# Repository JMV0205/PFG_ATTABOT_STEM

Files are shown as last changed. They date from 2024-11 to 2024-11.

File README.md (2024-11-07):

# PROYECTO FINAL DE GRADUACION ATTABOT STEM: Jimena Murillo Vargas
# Resumen
El rediseño del Atta-Bot STEM se centró en transformar el robot educativo en una herramienta más precisa, segura y funcional para entornos de aprendizaje. A través de un análisis técnico, se identificaron áreas de mejora que llevaron al desarrollo de un chasis robusto, diseñado para soportar el uso constante y facilitar la integración de herramientas educativas, incluso en condiciones de alta manipulación.
Una de las principales mejoras es la incorporación de un marcador, que permite al robot realizar actividades de trazado y dibujo, enriqueciendo su funcionalidad en la enseñanza. Además, se implementó un algoritmo de control proporcional-integral (PI), sustentado matemáticamente, que optimiza la precisión en los movimientos del robot, contribuyendo a un funcionamiento eficiente en diversas aplicaciones. La validación del prototipo demostró que cumple con los estándares técnicos establecidos, confirmando su aptitud como recurso didáctico en la enseñanza de conceptos STEM.

**Palabras Clave:** Robótica Educativa, Atta-Bot STEM, Controlador PI, Chasis, Dibujo interactivo. 

# Objetivos
**General**
1.	Adaptar el robot educativo del proyecto Atta-Bot STEM para que sea preciso, protegido y con mayor funcionalidad, para un entorno educativo de manipulación constante, que el prototipo actual.

**Específicos**

1.1	 Evaluar el robot Atta-Bot STEM en función de los criterios clave para un robot educativo efectivo para el diagnóstico de falencias.

1.2	 Diseñar un chasis protector para que sea adecuado en un entorno de enseñanza.

1.3	 Diseñar un algoritmo de control que mejore la precisión de los movimientos del robot ante condiciones de uso delimitadas.

1.4	 Validar el rediseño del robot Atta-Bot STEM para la comprobación del cumplimiento de los estándares educativos y técnicos establecidos en el proyecto Atta-Bot STEM.

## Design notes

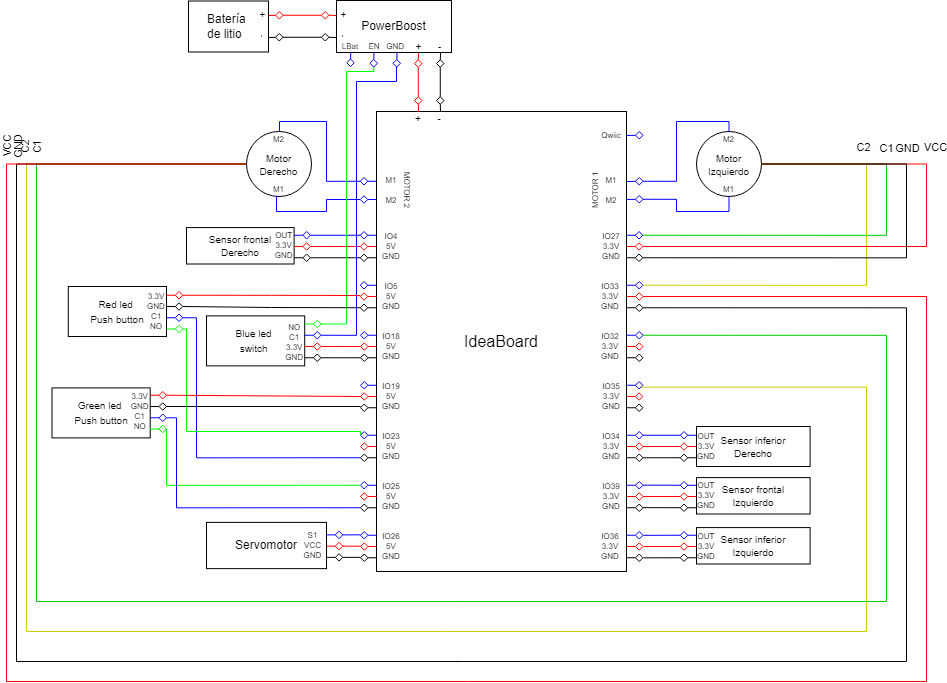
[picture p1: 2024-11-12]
Entregables/Diagrama electrico/Diagrama_electrico_PFG.png

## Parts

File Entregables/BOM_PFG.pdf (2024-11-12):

Cantidad | Nombre | # de Parte | Link | Costo
2 | Motor DC con
encoder | ROB-CB0N20 | https://www.crcibernetica.com/n20-gearmotor-with-encoder-and-wheel/ $14.95
1 | Batería Lipo | ADA-328 | https://www.crcibernetica.com/lithium-ion-polymer-battery-3-7v-
| | | 2500mah/ | $17.95
1 | Boost Battery
| Manager | ADA-2465 | https://www.crcibernetica.com/powerboost-1000-charger-rechargeable-5v-
| | | lipo-usb-boost-1a-1000c/ | $32.95
2 | Soporte Motor | ROB-CB02443 | https://www.crcibernetica.com/micro-gearmotor-support-bracket/ | $0.75
1 | Ball Caster | ROB-CB1818 | https://www.crcibernetica.com/3pi-n20-ball-caster/ | $2.75
1 | IdeaBoard | ROB-CBIB01 | https://www.crcibernetica.com/crcibernetica-ideaboard/ | $39.95
1 | Servomotor MG90S | MG90S | https://www.crcibernetica.com/mg90s-micro-servo-with-metal-gears/ | $6.95
2 | Infrarrojo delantero | SEN-CB0006 | https://www.crcibernetica.com/infrared-obstacle-avoidance-module/ | $2.95
2 | Infrarrojo abajo | SEN-CB0005 | https://www.crcibernetica.com/track-sensor-module/ | $1.95
1 | Kit conectores | KIT-CB0012 | https://www.crcibernetica.com/dupont-connector-assorted-kit/ | $8.95
1 | Kit espaciadores | TOL-CB0513 | https://www.crcibernetica.com/m3-nylon-screw-black-hex-screw-nut-nylon-pcb-
| | | standoff-assortment-kit-250pcs/ | $15.95
1 | Ribon Cable | CAB-10646 | https://www.crcibernetica.com/ribbon-cable-6-wire-15ft/ | $4.50
1 | Red Led push button | - | https://www.amazon.com/dp/B0C1GM39C2?ref=ppx_yo2ov_dt_b_fed_asin_title&t
| | | h=1 | $8.99
1 | Green Led push
| button | - | https://www.amazon.com/dp/B0C1GQ4JLB?ref=ppx_yo2ov_dt_b_fed_asi
| | | n_title&th=1 | $9.99
1 | Blue Led Switch | - | https://www.amazon.com/dp/B0CQ421KVZ?ref=ppx_yo2ov_dt_b_fed_asi
| | | n_title | $9.90

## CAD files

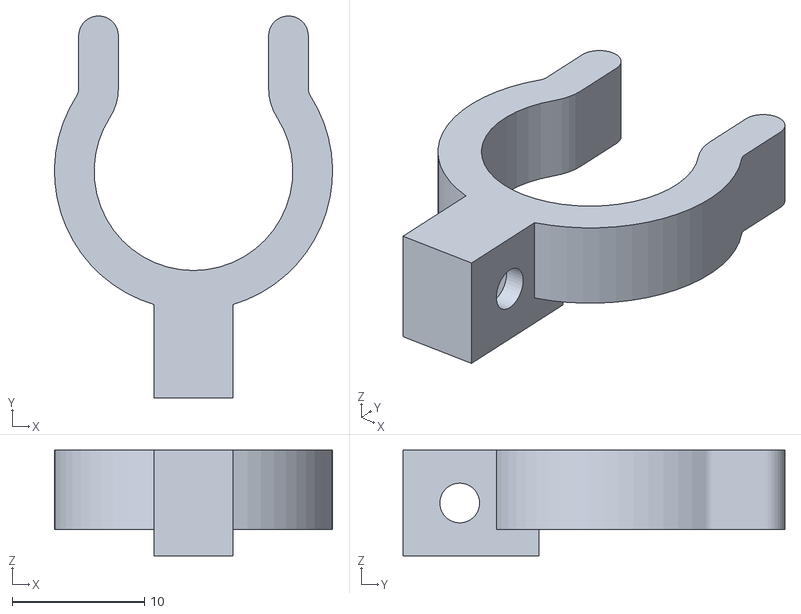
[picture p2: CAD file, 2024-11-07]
Entregables/Chasis/STL_DSK_PLANOS_CORTE/Sujetador_De_Marcador_2Largo_FULL.STL
21.0 x 28.8 x 8.00

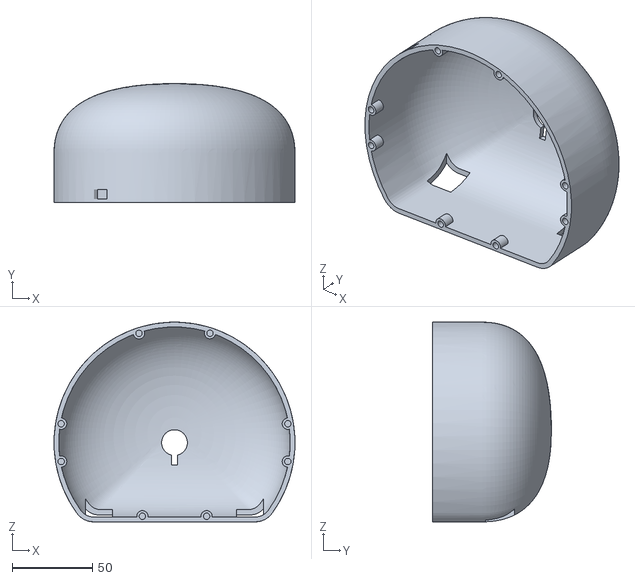
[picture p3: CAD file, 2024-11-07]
Entregables/Chasis/STL_DSK_PLANOS_CORTE/Prueba_chasis_Full.STL
150.0 x 74.0 x 124.3

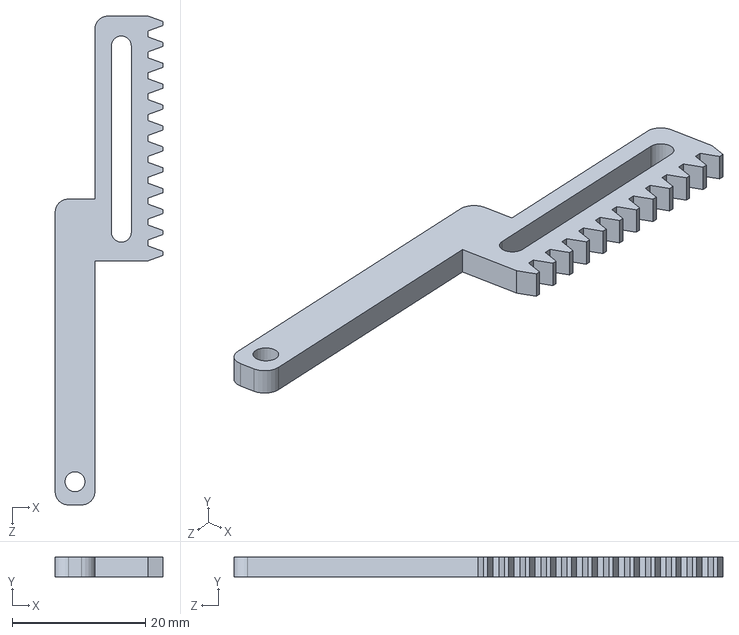
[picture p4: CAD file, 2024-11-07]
Entregables/Chasis/Pieza_de_cremallera_Lapicero_FULL.SLDPRT
16.2 x 3.00 x 73.5 mm

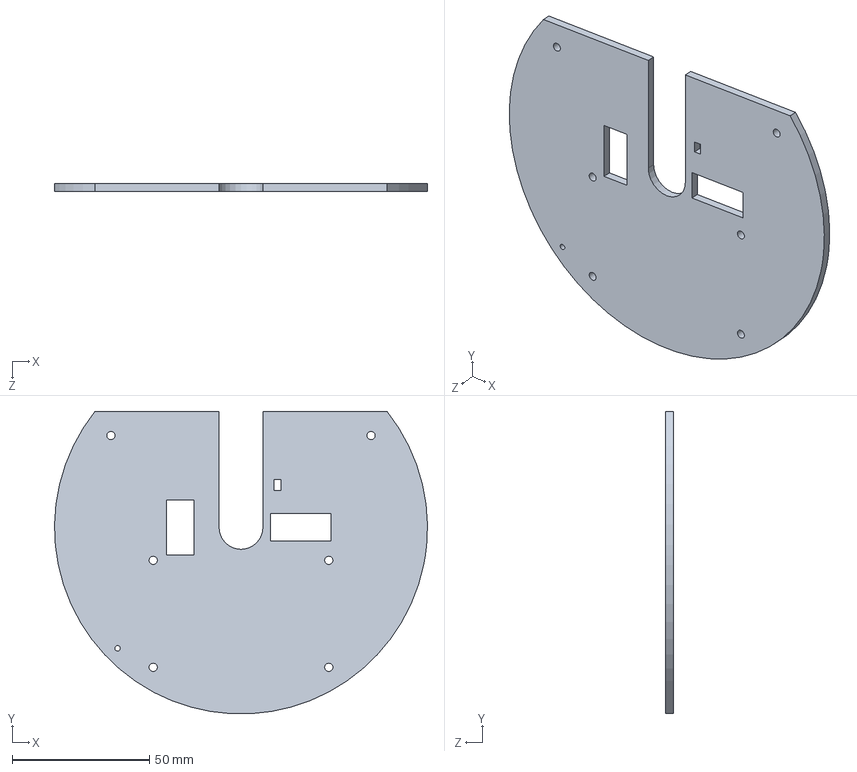
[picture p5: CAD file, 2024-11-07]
Entregables/Chasis/Nivel_interno_V2.SLDPRT
136.0 x 110.2 x 3.00 mm

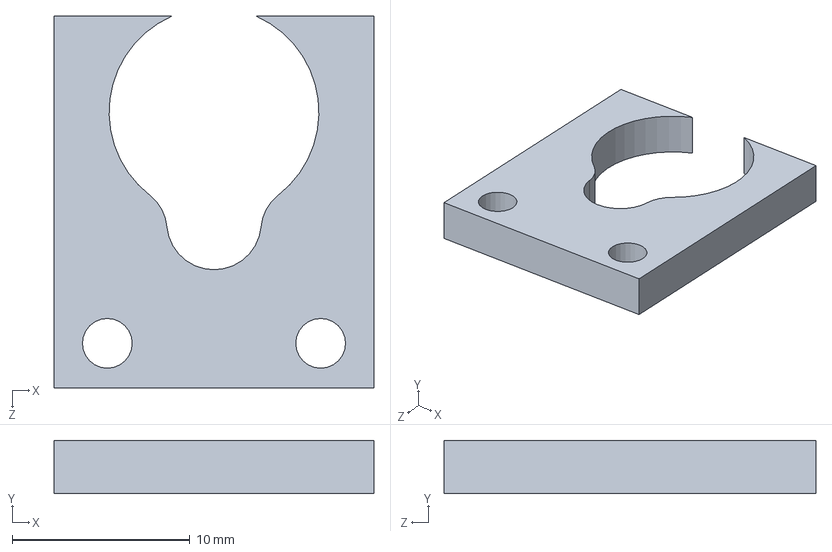
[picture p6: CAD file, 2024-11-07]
Entregables/Chasis/Pieza_SujecionMotorLift_5_final_si.SLDPRT
18.0 x 3.00 x 20.9 mm

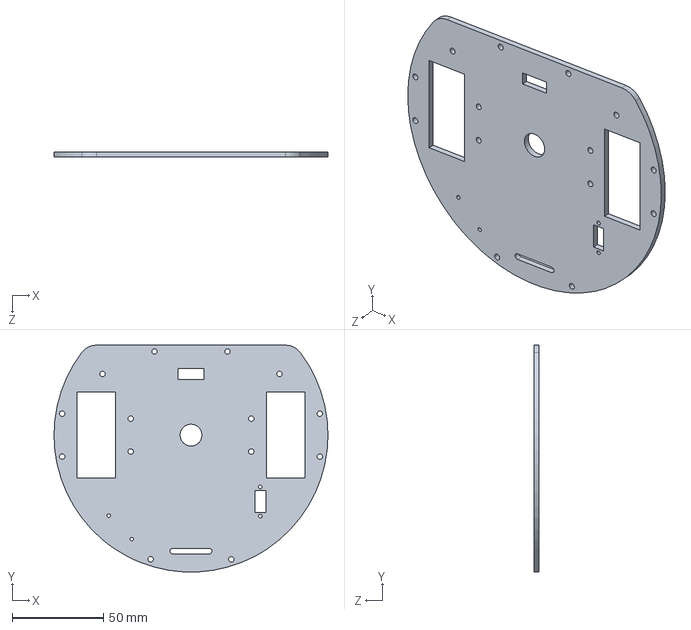
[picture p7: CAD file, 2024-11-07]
Entregables/Chasis/Base_Chasis_V3.SLDPRT
150.0 x 124.2 x 3.00 mm

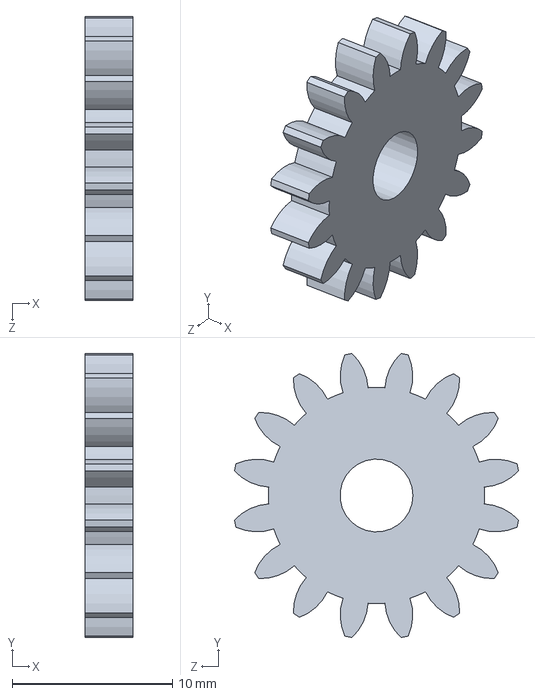
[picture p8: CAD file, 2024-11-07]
Entregables/Chasis/Pieza_EngraneLift_2.SLDPRT
3.00 x 17.7 x 17.7 mm

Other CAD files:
Entregables/Chasis/Sujetador_De_Marcador_2Largo_FULL.SLDPRT
Entregables/Chasis/Prueba_chasis_FULL.SLDPRT

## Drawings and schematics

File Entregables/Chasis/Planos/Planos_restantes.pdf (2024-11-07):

4 | 1 3 | 2

E

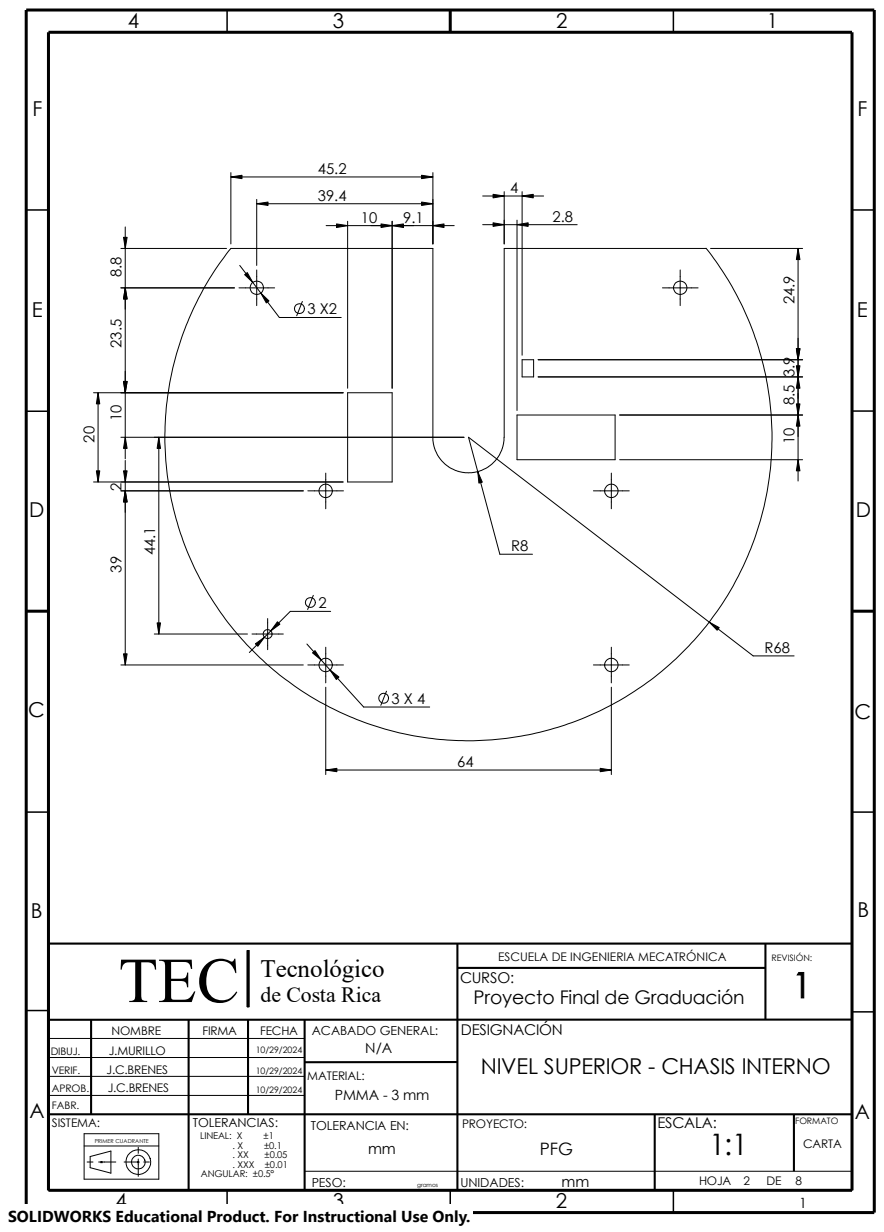
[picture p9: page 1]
Tecnológico TEC; PRIMER CUADRANTE; PMMA - 3 mm; REVISIÓN:; MATERIAL:

ESCUELA DE INGENIERIA MECATRÓNICA
CURSO:
Proyecto Final de Graduación

de Costa Rica

NOMBRE | FIRMA | FECHA | ACABADO GENERAL: N/A | DESIGNACIÓN NIVEL SUPERIOR - CHASIS INTERNO

DIBUJ. | J.MURILLO | | 10/29/2024
VERIF. | J.C.BRENES | | 10/29/2024
APROB. | J.C.BRENES | | 10/29/2024
FABR.
SISTEMA: | | | TOLERANCIAS: LINEAL: X ±1 . X ±0.1 . XX ±0.05 . XXX ±0.01 ANGULAR: ±0.5° | TOLERANCIA EN: mm | PFG | ESCALA: 1:1 | FORMATO PROYECTO: CARTA

PESO: gramos | mm UNIDADES: | HOJA 2 DE 8

SOLIDWORKS Educational Product. For Instructional Use Only.

E

F

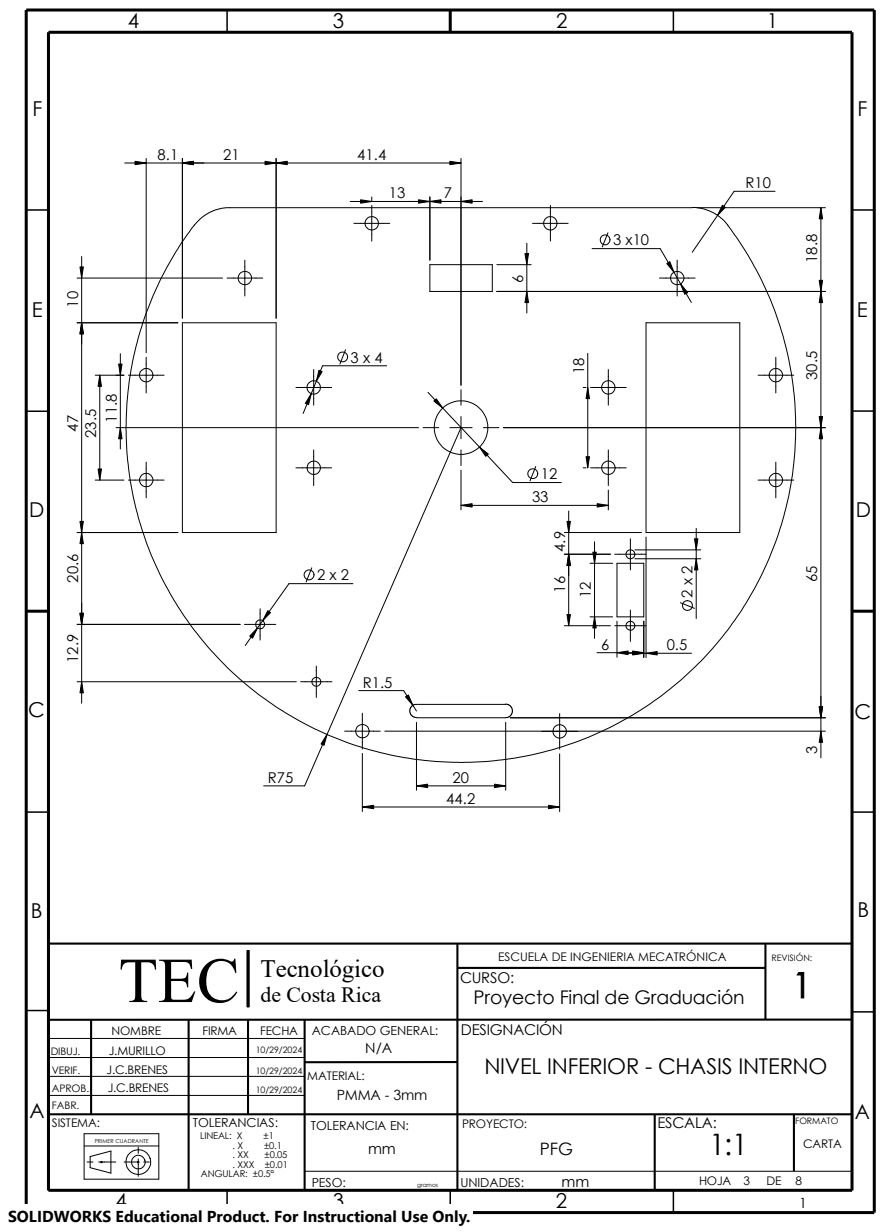
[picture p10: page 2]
Tecnológico TEC; PMMA - 3mm; REVISIÓN:; MATERIAL:

ESCUELA DE INGENIERIA MECATRÓNICA
CURSO:
Proyecto Final de Graduación

de Costa Rica

NOMBRE | FIRMA | FECHA | ACABADO GENERAL: N/A | DESIGNACIÓN NIVEL INFERIOR - CHASIS INTERNO

DIBUJ. | J.MURILLO | | 10/29/2024
VERIF. | J.C.BRENES | | 10/29/2024
APROB. | J.C.BRENES | | 10/29/2024
FABR.
SISTEMA: | | | TOLERANCIAS: | TOLERANCIA EN: | | ESCALA: 1:1 | FORMATO PROYECTO:

E

F

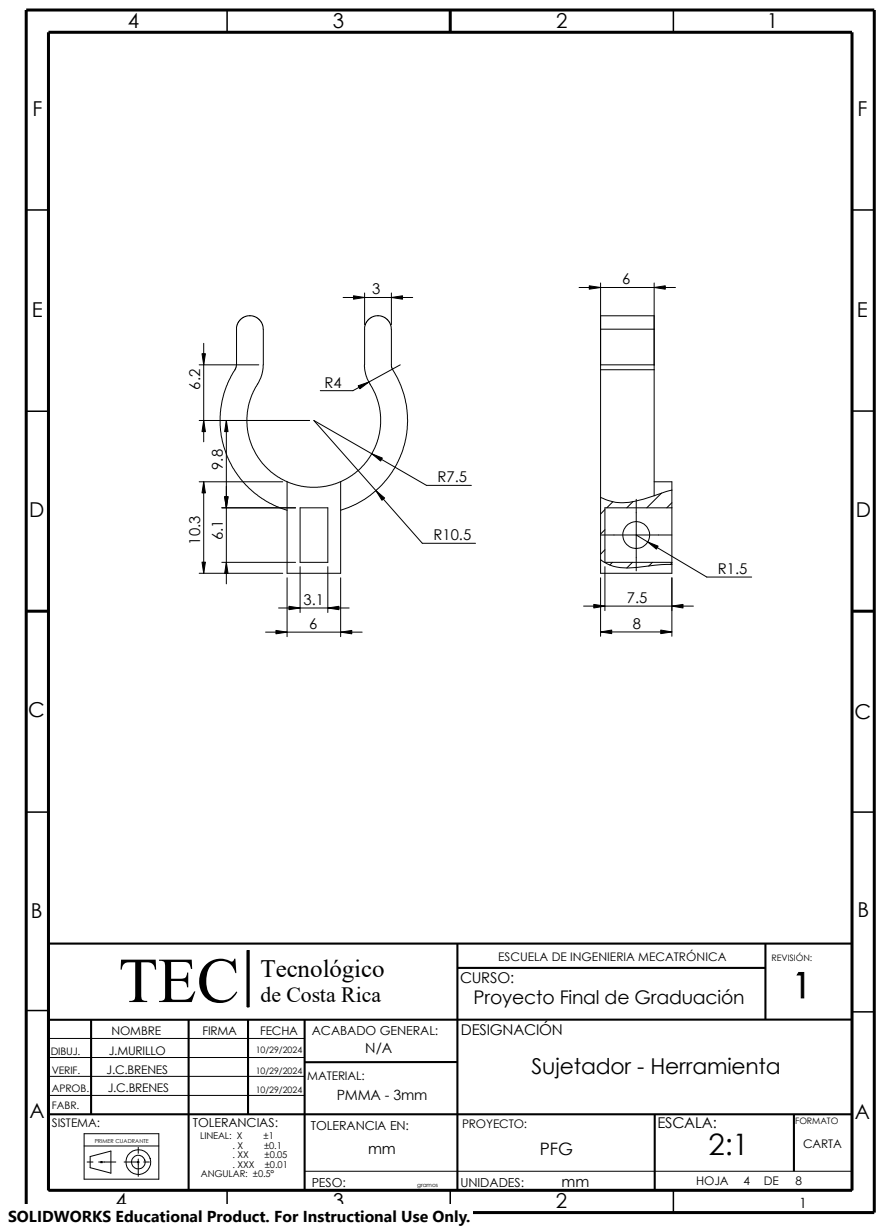
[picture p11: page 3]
Tecnológico TEC; PMMA - 3mm; REVISIÓN:; MATERIAL:

ESCUELA DE INGENIERIA MECATRÓNICA
CURSO:
Proyecto Final de Graduación

de Costa Rica

NOMBRE | FIRMA | FECHA | ACABADO GENERAL: N/A | DESIGNACIÓN Sujetador - Herramienta

DIBUJ. | J.MURILLO | | 10/29/2024
VERIF. | J.C.BRENES | | 10/29/2024
APROB. | J.C.BRENES | | 10/29/2024
FABR.
SISTEMA: | | | TOLERANCIAS: | TOLERANCIA EN: | | ESCALA: 2:1 | FORMATO PROYECTO:

18

E

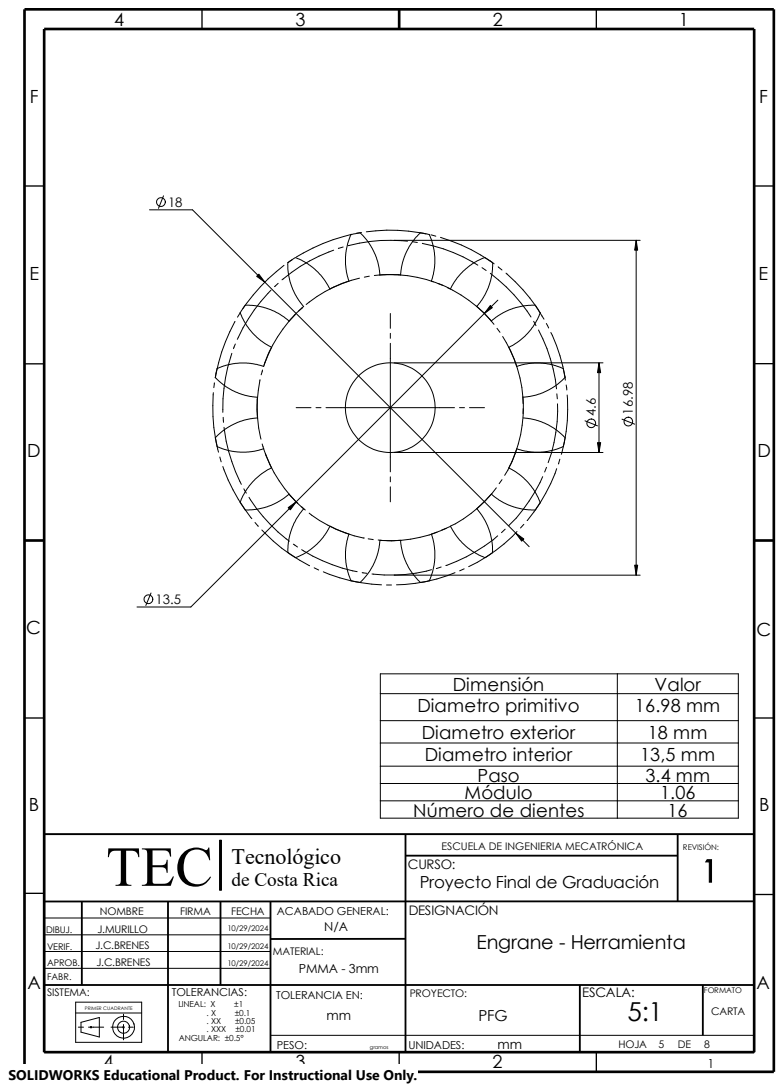
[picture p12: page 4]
Tecnológico TEC; PMMA - 3mm; REVISIÓN:; MATERIAL:; Diametro exterior; Número de dientes

Dimensión | Valor
Diametro primitivo | 16.98 mm

Diametro interior | 13,5 mm
Paso | 3.4 mm
Módulo | 1.06

ESCUELA DE INGENIERIA MECATRÓNICA
CURSO:
Proyecto Final de Graduación

de Costa Rica

NOMBRE | FIRMA | FECHA | ACABADO GENERAL: N/A | DESIGNACIÓN Engrane - Herramienta

DIBUJ. | J.MURILLO | | 10/29/2024
VERIF. | J.C.BRENES | | 10/29/2024
APROB. | J.C.BRENES | | 10/29/2024
FABR.
SISTEMA: | | | TOLERANCIAS: | TOLERANCIA EN: | | ESCALA: 5:1 | FORMATO PROYECTO:

E

F

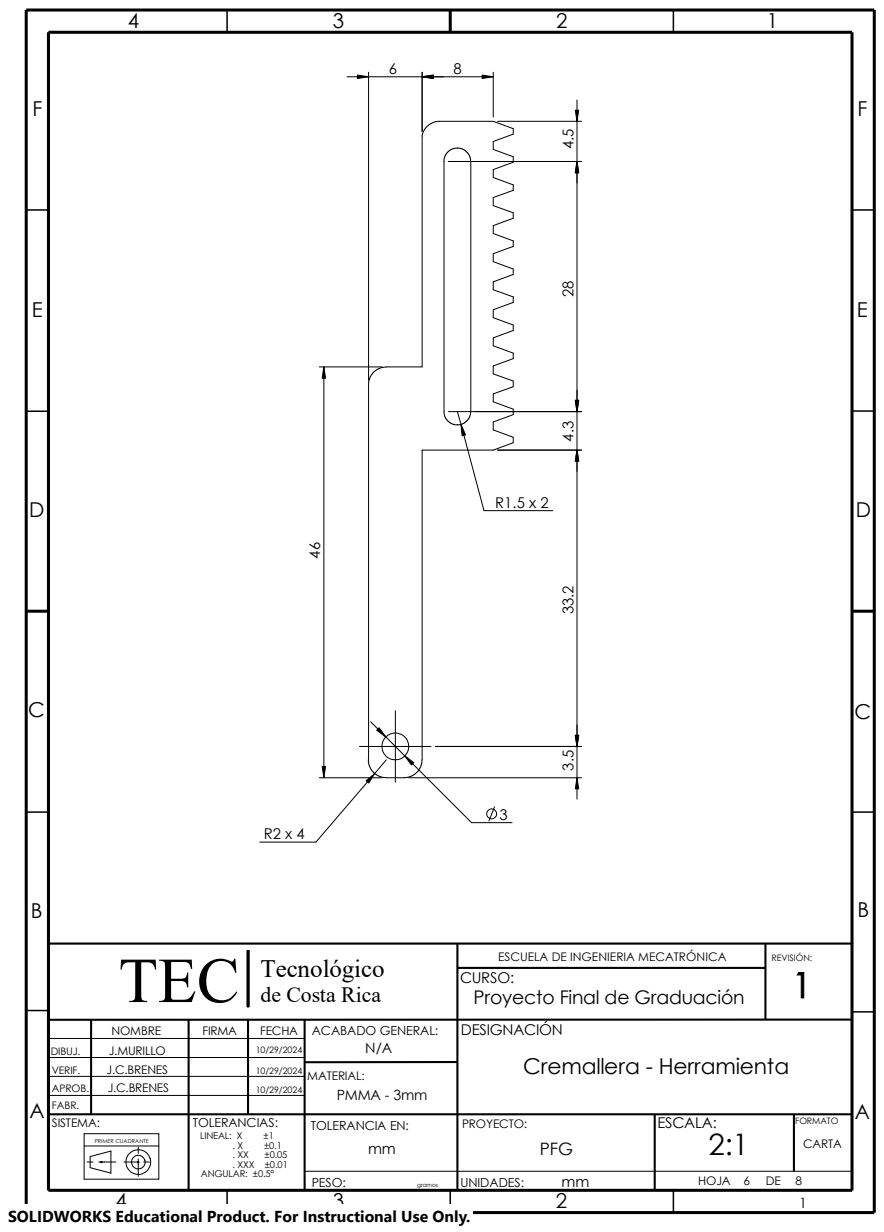
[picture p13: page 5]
Tecnológico TEC; PMMA - 3mm; REVISIÓN:; MATERIAL:

ESCUELA DE INGENIERIA MECATRÓNICA
CURSO:
Proyecto Final de Graduación

de Costa Rica

NOMBRE | FIRMA | FECHA | ACABADO GENERAL: N/A | DESIGNACIÓN Cremallera - Herramienta

DIBUJ. | J.MURILLO | | 10/29/2024
VERIF. | J.C.BRENES | | 10/29/2024
APROB. | J.C.BRENES | | 10/29/2024
FABR.
SISTEMA: | | | TOLERANCIAS: | TOLERANCIA EN: | | ESCALA: | FORMATO PROYECTO:

E

F

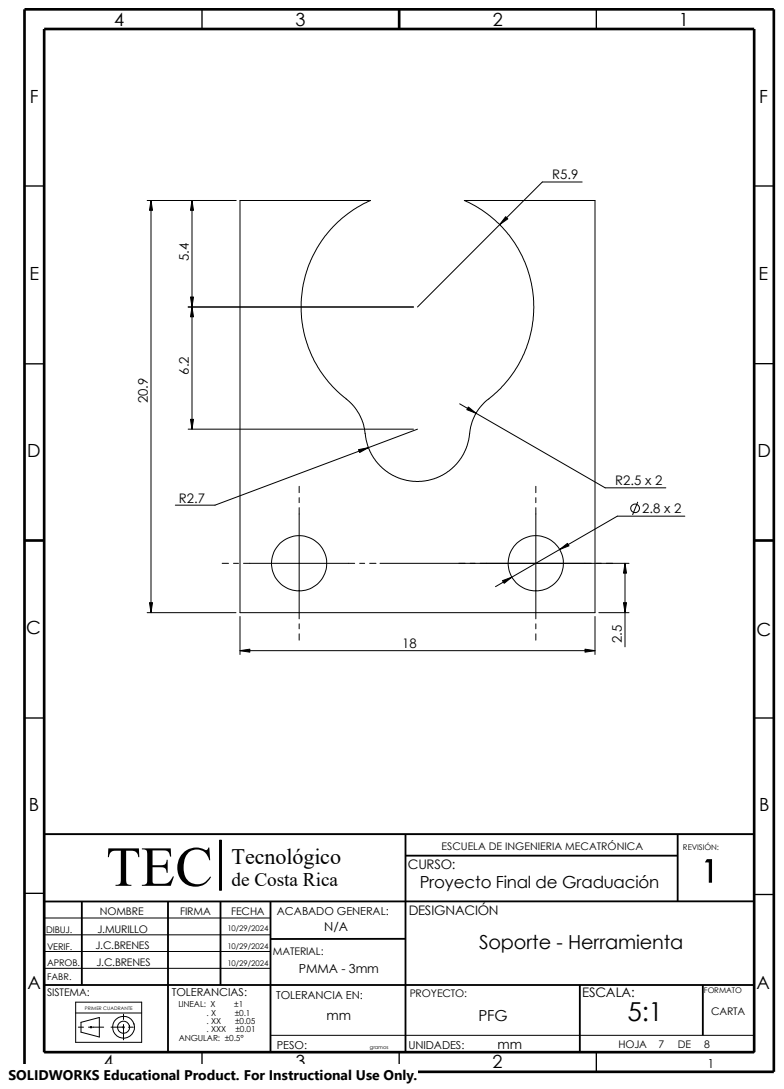
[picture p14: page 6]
Tecnológico TEC; PMMA - 3mm; REVISIÓN:; MATERIAL:

ESCUELA DE INGENIERIA MECATRÓNICA
CURSO:
Proyecto Final de Graduación

de Costa Rica

NOMBRE | FIRMA | FECHA | ACABADO GENERAL: N/A | DESIGNACIÓN Soporte - Herramienta

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

E

F

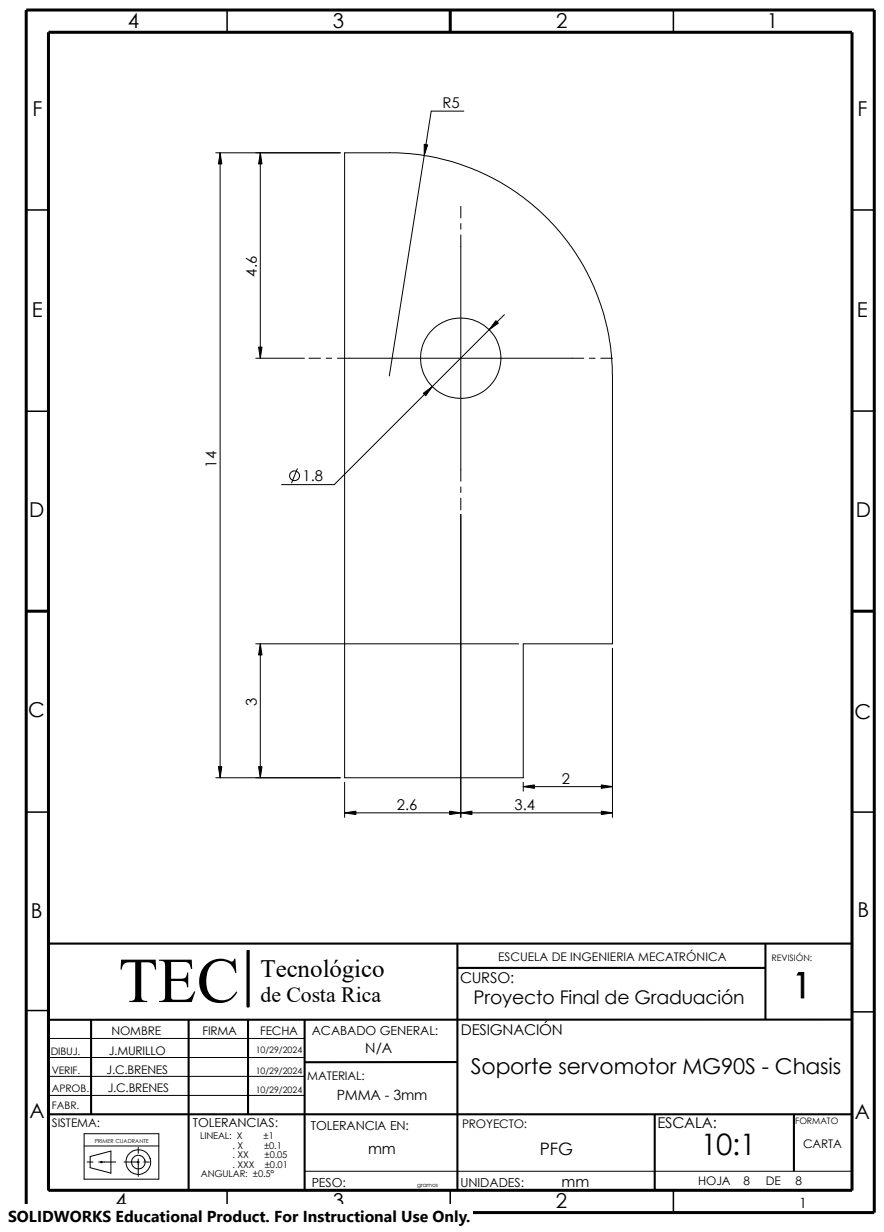
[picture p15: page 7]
Tecnológico TEC; PMMA - 3mm; REVISIÓN:; MATERIAL:

ESCUELA DE INGENIERIA MECATRÓNICA
CURSO:
Proyecto Final de Graduación

de Costa Rica

NOMBRE | FIRMA | FECHA | ACABADO GENERAL: N/A | DESIGNACIÓN Soporte servomotor MG90S - Chasis

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

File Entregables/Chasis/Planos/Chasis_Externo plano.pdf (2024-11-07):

B

A

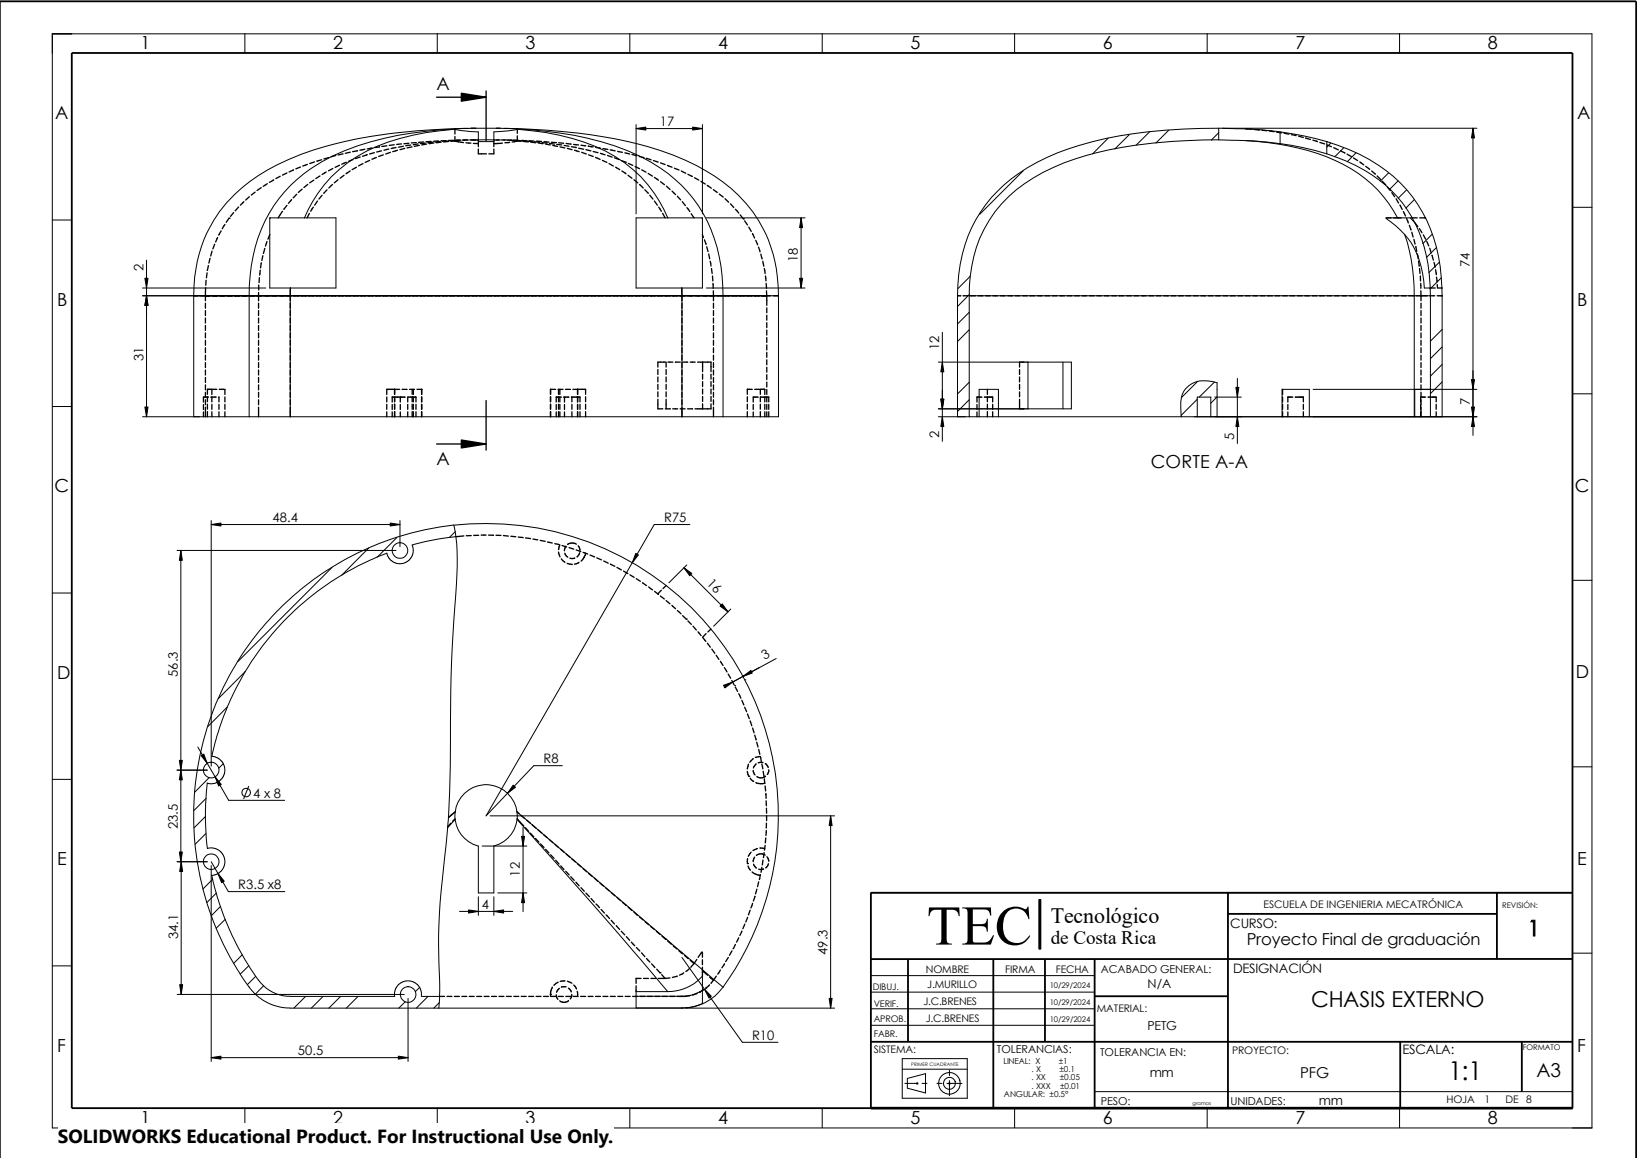
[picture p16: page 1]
Tecnológico TEC; PRIMER CUADRANTE; CURSO:; MATERIAL:; REVISIÓN:; PETG; HOJA; CORTE A-A

ESCUELA DE INGENIERIA MECATRÓNICA
Proyecto Final de graduación

de Costa Rica

NOMBRE | FIRMA | FECHA | ACABADO GENERAL: N/A | DESIGNACIÓN CHASIS EXTERNO

DIBUJ. | J.MURILLO | | 10/29/2024
VERIF. | J.C.BRENES | | 10/29/2024
APROB. | J.C.BRENES | | 10/29/2024
FABR.
SISTEMA: | | | LINEAL: X ±1 . X ±0.1 . XX ±0.05 . XXX ±0.01 ANGULAR: ±0.5° | TOLERANCIA EN: TOLERANCIAS: mm | PROYECTO: PFG | ESCALA: 1:1 | FORMATO A3

PESO: gramos | UNIDADES: mm

SOLIDWORKS Educational Product. For Instructional Use Only.

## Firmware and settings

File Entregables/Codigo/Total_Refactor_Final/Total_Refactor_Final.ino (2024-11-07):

#include <ESP32Servo.h>

// Robot constants
const int samplingTime = 25; // units: miliseconds
const float pulsesPerRev = 574; // number of pulses from a single encoder output
const float wheelRadius = 22.5; // Wheel circumference = 139.5mm
const float distanceWheelToWheel = 104;
const float distanceCenterToWheel = distanceWheelToWheel / 2 ; // Turning radius of the robot, distance in mm between the center and one wheel

// Constants for PID control with samplingTime = 25ms
const float targetSpeed = 120.0; // Target speed for the robot in mm/s
const float kpSpeed = 0.75; // Proportional constant for speed control
const float kiSpeed = 2; // Integral constant for speed control
const float kdSpeed = 0.0; // Derivative constant for speed control (set to zero for no derivative action)

// Constants for PID control implementation
const int minIntegralErrorSpeed = -255; // Minimum value for integral error to avoid windup
const int maxIntegralErrorSpeed = 255; // Maximum value for integral error to avoid windup

const int upperDutyCycleLimitSpeed = 200; // Maximum allowed PWM value for speed control
const int lowerDutyCycleLimitSpeed = 60; // Minimum allowed PWM value for speed control

// Error accumulation for speed PID control
float sumErrorVelRight = 0; // Accumulated integral error for the right wheel
float prevErrorVelRight = 0; // Previous error value for the right wheel (used for derivative calculation)
float sumErrorVelLeft = 0; // Accumulated integral error for the left wheel
float prevErrorVelLeft = 0; // Previous error value for the left wheel (used for derivative calculation)

int distanceTraveled = 0; // Variable to track the total distance traveled by the robot
const float correctionFactorLines = 0.92; 


int prevPWMRight = 0;
int prevPWMLeft = 0;

// For speed sampling
unsigned long previousTime = 0;

// Variables to keep track of the encoder state
volatile long leftEncoderPos = 0; // Current position of the left encoder (in ticks)
long leftTicksForSpeed = 0; // Number of encoder ticks counted for left wheel speed calculation
long leftPrevTicks = 0; // Previous encoder tick count for the left wheel (used to calculate speed) 
volatile long rightEncoderPos = 0; // Current position of the right encoder (in ticks)
long rightTicksForSpeed = 0; // Number of encoder ticks counted for right wheel speed calculation
long rightPrevTicks = 0; // Previous encoder tick count for the right wheel (used to calculate speed)

// Variables to store the servo position
const int activateAngle = 110;  // Activated Tool
const int deactivateAngle = 180; // Deactivated Tool
int set = 0;


// Create a Servo object to control the MG90S
Servo myServo;


// Define pin for the servo signal
const int servoPin = 26;

// Define the encoder pins
const int rightEncoderA = 27; // Pin for the right encoder's channel A
const int rightEncoderB = 33; // Pin for the right encoder's channel B

const int leftEncoderA = 32; // Pin for the left encoder's channel A
const int leftEncoderB = 35; // Pin for the left encoder's channel B

// Motor control pins
const int rightMotorM1 = 13;   // Direction control pin 1 for the right motor
const int rightMotorM2 = 15;   // Direction control pin 2 for the right motor


const int leftMotorM1 = 14;   // Direction control pin 1 for the left motor
const int leftMotorM2 = 12;   // Direction control pin 1 for the left motor

// Obstacle sensors setup
const int rightInfraredSensor = 4; // Pin for the right infrared obstacle sensor
const int leftInfraredSensor = 34;  // Pin for the right infrared obstacle sensor

// Tracker sensors setup
const int rightTrackerSensor = 36;  // Pin for the right tracker sensor
const int leftTrackerSensor = 39;   // Pin for the left tracker sensor

// Buttons setup
const int startButtonPin = 14;      // Pin for the start button
const int stopButtonPin = 15;       // Pin for the stop button

int currentStep = 0; // Variable to keep track of the current step
unsigned long stepStartTime = 0; // Variable to track the start time of each step

//******************************************************************************************************************
// Function that updates the position of the right wheel encoder.
//
// This function increments the encoder position counter for the right wheel each time it is called. The counter 
// reflects the accumulated encoder pulses, allowing for the calculation of distance or speed based on pulses.
//
//******************************************************************************************************************
void rightUpdateEncoder() {
  // Update encoder positions based on direction
  rightEncoderPos ++;

}

//******************************************************************************************************************
// Function that updates the position of the left wheel encoder.
//
// This function increments the encoder position counter for the left wheel each time it is called. The counter 
// reflects the accumulated encoder pulses, which can be used to determine distance or speed based on pulse count.
//
//******************************************************************************************************************
void leftUpdateEncoder() {
  // Update encoder positions based on direction
  leftEncoderPos ++;
}


void setup() {

  // Set the PWM properties (50 Hz is typical for servos)
  myServo.setPeriodHertz(50);    // Standard 50Hz servo
  myServo.attach(servoPin, 500, 2400);  // Attach the servo on the pin with min/max pulse widths

  // Set encoder pins as inputs
  pinMode(rightEncoderA, INPUT_PULLUP);
  pinMode(rightEncoderB, INPUT_PULLUP);

  pinMode(leftEncoderA, INPUT_PULLUP);
  pinMode(leftEncoderB, INPUT_PULLUP);

  pinMode(rightMotorM1, OUTPUT);
  pinMode(rightMotorM2, OUTPUT);

  pinMode(leftMotorM1, OUTPUT);
  pinMode(leftMotorM2, OUTPUT);

  //Obstacle sensors set up
  pinMode(rightInfraredSensor, INPUT);
  pinMode(leftInfraredSensor, INPUT);

  // Tracker sensors set up
  pinMode(rightTrackerSensor, INPUT);
  pinMode(leftTrackerSensor, INPUT);

  //Buttons set up
  pinMode(startButtonPin, INPUT_PULLUP);
  pinMode(stopButtonPin, INPUT_PULLUP);

  // Attach interrupts to encoder pins
  attachInterrupt(digitalPinToInterrupt(rightEncoderA), rightUpdateEncoder, CHANGE);
  attachInterrupt(digitalPinToInterrupt(rightEncoderB), rightUpdateEncoder, CHANGE);

  attachInterrupt(digitalPinToInterrupt(leftEncoderA), leftUpdateEncoder, CHANGE);
  attachInterrupt(digitalPinToInterrupt(leftEncoderB), leftUpdateEncoder, CHANGE);

}


void loop() {
}

//******************************************************************************************************************
// Function that controls the servo based on the variable `set`. If `set` is 1, the tool is activated; otherwise, it is deactivated.
//
// This function adjusts the servo angle to activate or deactivate the tool based on the `set` value.
//
// @param set Value that determines whether the tool is activated (1) or deactivated (0).
//
// @return true Returns true upon successful action.
//******************************************************************************************************************
bool controlServo(int set) {
  if (set == 1) {
    // Activate the tool by setting it to 110 degrees
    myServo.write(activateAngle);
  } else { //Deactivate the tool by setting it to 180 degrees
    myServo.write(deactivateAngle);
  }
  return true;  // Action completed
}

//******************************************************************************************************************
// Function that controls the speed of the wheels using a PID controller based on the reference and actual speeds.
//
// This function calculates a PWM output for the motors by applying a PID control loop to match the actual speed to a setpoint.
//
// @param refSpeed The target speed for the motor.
// @param actualSpeed The current speed of the motor.
// @param sumErrorSpeed Accumulated integral error for the speed PID.
// @param prevErrorSpeed Previous speed error for the derivative calculation.
//
// @return The computed PWM signal as an integer to control the motor speed.
//******************************************************************************************************************
int controlWheelSpeed(float refSpeed, float actualSpeed, float& sumErrorSpeed, float& prevErrorSpeed) {
  
  // Calculate the error between the reference speed and the actual speed
  float errorSpeed = refSpeed - actualSpeed;

  // Update the integral error by accumulating the current error over time
  // Multiply by 0.01 to scale the contribution of the error (based on sampling time)
  sumErrorSpeed += errorSpeed * 0.01;

  // Constrain the integral error to avoid windup
  sumErrorSpeed = constrain(sumErrorSpeed, minIntegralErrorSpeed , maxIntegralErrorSpeed);

  // Calculate the derivative of the error (difference between current and previous error)
  float diffErrorSpeed = (errorSpeed - prevErrorSpeed);

  // PID control equation to calculate the control output
  float pidOutput = (kpSpeed * errorSpeed) + (kiSpeed * sumErrorSpeed) + (kdSpeed * diffErrorSpeed);

  // Constrain the PID output to avoid saturation and ensure it stays within motor PWM limits
  pidOutput = constrain((int)pidOutput, lowerDutyCycleLimitSpeed, upperDutyCycleLimitSpeed);

  // Update the previous error for the next iteration of the control loop
  prevErrorSpeed = errorSpeed;
  
  // Return the calculated PWM value as an integer
  return (int)pidOutput;
}

//******************************************************************************************************************
// Function that moves the robot a desired linear distance using PID control to maintain speed and direction.
//
// This function continuously calculates the speed of each wheel, adjusts the motor PWM values, and checks if the robot has reached the desired distance.
//
// @param desiredDistance The target distance in mm that the robot should travel.
//
// @return true if the desired distance is reached; false otherwise.
//******************************************************************************************************************
bool advanceDesiredDistance(int desiredDistance) {

  // Flag to indicate if the robot should move in reverse
  bool reverse = false;

  // Create a time condition using millis to apply a sampling time without delays
  unsigned long currentTime = millis(); // Get the current time in milliseconds
  unsigned long deltaTime = currentTime - previousTime; // Time elapsed since the last sample

  // Check if the elapsed time has reached the sampling time (10 ms)
  if (deltaTime >= samplingTime) {
    previousTime = currentTime; // Reset previous time for the next sample

    // Convert deltaTime to seconds
    float deltaTimeSec = deltaTime / 1000.0;


    // Calculate the number of encoder ticks since the last sample
    rightTicksForSpeed = rightEncoderPos - rightPrevTicks;
    leftTicksForSpeed = leftEncoderPos - leftPrevTicks;

    
    // Calculate the current speeds of both wheels based on the encoder ticks
    float actualSpeedLeft = calculateSpeed(leftTicksForSpeed, deltaTimeSec); // Speed of the left wheel in mm/s
    float actualSpeedRight = calculateSpeed(rightTicksForSpeed, deltaTimeSec); // Speed of the right wheel in mm/s

    // Update the previous encoder tick counts
    rightPrevTicks = rightEncoderPos;
    leftPrevTicks = leftEncoderPos;


    // Set desired speeds

    if (desiredDistance < 0) { // If the desired distance is negative, move in reverse
        reverse = true;
    }

    float speedSetPoint = targetSpeed; // Define the target speed for both wheels (in mm/s)

    // PID control loop for speed to calculate PWM values for both wheel
    int pwmRightWheel = controlWheelSpeed(speedSetPoint, actualSpeedRight, sumErrorVelRight, prevErrorVelRight);
    int pwmLeftWheel = controlWheelSpeed(speedSetPoint, actualSpeedLeft, sumErrorVelLeft, prevErrorVelLeft);



    // Determine if the PWM values for the right and left wheels have changed
    bool rightChanged = (prevPWMRight != pwmRightWheel); // Check if right wheel needs to be updated
    bool leftChanged = (prevPWMLeft != pwmLeftWheel); // Check if left wheel needs to be updated

    // Update the H-Bridge configuration if there are changes in the PWM values
    if (rightChanged) {
      configureHBridge(reverse, 1, pwmRightWheel, pwmLeftWheel);// Update the right motor control
    }
    if (leftChanged) {
      configureHBridge(reverse, 2, pwmRightWheel, pwmLeftWheel);// Update the left motor control
    }
    if (rightChanged && leftChanged) {
      configureHBridge(reverse, 3, pwmRightWheel, pwmLeftWheel); // Update both motors if both values changed
    }

    // Store the current PWM values for comparison in the next iteration
    prevPWMRight = pwmRightWheel;
    prevPWMLeft = pwmLeftWheel;

    
    // Calculate the distance traveled by the robot using encoder data
    float distanceTraveled = calculateLinearDistanceTraveled(leftEncoderPos, rightEncoderPos);

    // Check if the robot has traveled the desired distance
    if (abs(distanceTraveled) >= correctionFactorLines * abs(desiredDistance)) {

      // If the desired distance is reached, stop the robot
      configureHBridge(reverse, 3, 0, 0);

      // Reset PID control values
      sumErrorVelRight = 0;
      prevErrorVelRight = 0;
      sumErrorVelLeft = 0;
      prevErrorVelLeft = 0;

      // Reset encoder tick counts
      rightPrevTicks = 0;
      leftPrevTicks = 0;

      rightEncoderPos = 0;
      leftEncoderPos = 0;

      return true; // Return true to indicate that the desired distance has been reached
    }

  }
  return false; // Return false if the robot has not yet reached the desired distance
}

//******************************************************************************************************************
// Function that turns the robot to a specified angle using PID control for each wheel's speed.
//
// This function calculates the speed of each wheel, updates the H-Bridge configuration to turn, and checks if the robot has turned to the desired angle.
//
// @param desiredAngle The target angle in degrees for the robot to turn.
//
// @return true if the desired angle is reached; false otherwise.
//******************************************************************************************************************
bool turnDesiredAngle (int desiredAngle) {

  // Flag to indicate if the robot should turn in counterClockwise
  bool counterClockwise = false;

  if (desiredAngle < 0) { // If the desired angle is negative, move in counterClockwise
    counterClockwise = true;
  }

  // Create a time condition using millis to apply a sampling time without delays
  unsigned long currentTime = millis(); // Get the current time in milliseconds
  unsigned long deltaTime = currentTime - previousTime; // Time elapsed since the last sample


  // Calculate the linear distance required for the given angle
  float desiredDistance = calculateLinearDistanceDesired(desiredAngle);

  // Check if the elapsed time has reached the sampling time (10 ms)
  if (deltaTime >= samplingTime) {
    previousTime = currentTime; // Reset previous time for the next sample

    // Convert deltaTime to seconds
    float deltaTimeSec = deltaTime / 1000.0;


    // Calculate the number of encoder ticks since the last sample
    rightTicksForSpeed = rightEncoderPos - rightPrevTicks;
    leftTicksForSpeed = leftEncoderPos - leftPrevTicks;

    
    // Calculate the current speeds of both wheels based on the encoder ticks
    float actualSpeedLeft = calculateSpeed(leftTicksForSpeed, deltaTimeSec); // Speed of the left wheel in mm/s
    float actualSpeedRight = calculateSpeed(rightTicksForSpeed, deltaTimeSec); // Speed of the right wheel in mm/s

    // Update the previous encoder tick counts
    rightPrevTicks = rightEncoderPos;
    leftPrevTicks = leftEncoderPos;


    // Set desired speeds

    float speedSetPoint = targetSpeed; // Define the target speed for both wheels (in mm/s)

    // PID control loop for speed to calculate PWM values for both wheel
    int pwmRightWheel = controlWheelSpeed(speedSetPoint, actualSpeedRight, sumErrorVelRight, prevErrorVelRight);
    int pwmLeftWheel = controlWheelSpeed(speedSetPoint, actualSpeedLeft, sumErrorVelLeft, prevErrorVelLeft);

    // Determine if the PWM values for the right and left wheels have changed
    bool rightChanged = (prevPWMRight != pwmRightWheel); // Check if right wheel needs to be updated
    bool leftChanged = (prevPWMLeft != pwmLeftWheel); // Check if left wheel needs to be updated

    // Update the H-Bridge configuration if there are changes in the PWM values
    if (rightChanged) {
      configureHBridgeTurn(counterClockwise, 1, pwmRightWheel, pwmLeftWheel);// Update the right motor control
    }
    if (leftChanged) {
      configureHBridgeTurn(counterClockwise, 2, pwmRightWheel, pwmLeftWheel);// Update the left motor control
    }
    if (rightChanged && leftChanged) {
      configureHBridgeTurn(counterClockwise, 3, pwmRightWheel, pwmLeftWheel); // Update both motors if both values changed
    }

    // Store the current PWM values for comparison in the next iteration
    prevPWMRight = pwmRightWheel;
    prevPWMLeft = pwmLeftWheel;

    // Calculate the distance traveled by the robot using encoder data
    float distanceTraveled = calculateLinearDistanceTraveled(leftEncoderPos, rightEncoderPos);

    // Check if the robot has traveled the desired distance
    if (abs(distanceTraveled) >= abs(desiredDistance)) {

      // If the desired distance is reached, stop the robot
      configureHBridgeTurn(counterClockwise, 3, 0, 0);

      // Reset PID control values
      sumErrorVelRight = 0;
      prevErrorVelRight = 0;
      sumErrorVelLeft = 0;
      prevErrorVelLeft = 0;

      // Reset encoder tick counts
      rightPrevTicks = 0;
      leftPrevTicks = 0;

      rightEncoderPos = 0;
      leftEncoderPos = 0;

      return true; // Return true to indicate that the desired distance has been reached
    }

  }
  return false; // Return false if the robot has not yet reached the desired distance
}

//******************************************************************************************************************
// Function that calculates the speed of a wheel based on encoder pulses and elapsed time.
//
// The function converts the number of pulses into a linear distance, then calculates the speed in mm/s based on the time interval.
//
// @param pulses The number of encoder pulses detected.
// @param deltaTime The time interval in seconds.
//
// @return The calculated speed in mm/s.
//******************************************************************************************************************
float calculateSpeed(long pulses, float deltaTime) {
    // Wheel circumference in mm
    float wheelCircumference = 2 * 3.1416 * wheelRadius;

    // Full revolutions based on the number of pulses
    float revolutions = pulses / pulsesPerRev;

    // Distance traveled in mm
    float distance = revolutions * wheelCircumference;

    //Speed mm/s

    float vel = distance / deltaTime;
    
    return vel;
}

//******************************************************************************************************************
// Function that configures the H-Bridge to control forward or reverse motion of each wheel based on PWM values and direction.
//
// This function sets the PWM for each motor pin depending on the motion direction and update mode.
//
// @param reverse Boolean indicating whether to move in reverse (true) or forward (false).
// @param update Mode to update specific wheels: 1 for right, 2 for left, 3 for both.
// @param pwmRightWheel PWM value for the right wheel.
// @param pwmLeftWheel PWM value for the left wheel.
//******************************************************************************************************************
void configureHBridge(bool reverse, int update, int pwmRightWheel, int pwmLeftWheel){

    // Check if right wheel should be updated (update == 1 or update == 3)
    if (update == 1 || update == 3) {
        if (!reverse) { // Set right wheel for forward direction
            analogWrite(rightMotorM1, pwmRightWheel); // Apply PWM to right motor for forward motion
            analogWrite(rightMotorM2, 0);             // Set right motor reverse pin to 0 (off)
        } else { // Set right wheel for reverse direction
            analogWrite(rightMotorM1, 0);             // Set right motor forward pin to 0 (off)
            analogWrite(rightMotorM2, pwmRightWheel); // Apply PWM to right motor for reverse motion
        }
    }

    // Check if left wheel should be updated (update == 2 or update == 3)
    if (update == 2 || update == 3) {
        if (!reverse) { // Set left wheel for forward direction
            analogWrite(leftMotorM1, pwmLeftWheel); // Apply PWM to left motor for forward motion
            analogWrite(leftMotorM2, 0);            // Set left motor reverse pin to 0 (off)
        } else { // Set left wheel for reverse direction
            analogWrite(leftMotorM1, 0);            // Set left motor forward pin to 0 (off)
            analogWrite(leftMotorM2, pwmLeftWheel); // Apply PWM to left motor for reverse motion
        }
    }
}
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
